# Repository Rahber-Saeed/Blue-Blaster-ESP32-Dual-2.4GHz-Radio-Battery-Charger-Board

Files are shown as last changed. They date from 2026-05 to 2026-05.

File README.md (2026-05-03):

# Blue-Blaster-ESP32-Dual-2.4GHz-Radio-Battery-Charger-Board
A custom open-source ESP32 development board featuring the WROOM-32E module, integrated TP4056 Li-Ion/Li-Po battery charging, dual E01-ML01DP5 (nRF24L01+) 2.4GHz wireless modules, USB-C with CH340C, and an onboard 0.96" OLED display. Designed for advanced wireless projects, robotics, and handheld controllers.
# 🔵 Blue Blaster - ESP32 Dual-Radio Dev Board

Blue Blaster PCB Render

The **Blue Blaster** is a feature-packed, custom ESP32 development board designed for advanced wireless communication projects. It combines the power of the ESP32-WROOM-32E with dual 2.4GHz radio modules (E01-ML01DP5), seamless USB-C connectivity, and robust Li-Ion/Li-Po battery management. 

This board is perfect for building DIY remote controllers, IoT sensor hubs, RC robotics, or any project requiring robust data transfer between multiple devices.

> ⚠️ **Note:** This project is currently in the prototyping/design phase. Please review the schematic and ensure it suits your needs before ordering the PCB.

---

## ✨ Key Features

*   **Main Controller:** ESP32-WROOM-32E (4MB Flash).
*   **Power Management:**
    *   TP4056 Li-Ion/Li-Po battery charger with status LEDs.
    *   AMS1117 3.3V voltage regulator for main logic.
*   **Connectivity:**
    *   **USB Type-C:** Handles both power and data via the CH340C USB-to-Serial chip.
    *   **Dual 2.4GHz Radio:** Two E01-ML01DP5 modules (compatible with nRF24L01+ and SX1280 ecosystem) enabling master/slave or node-to-node communication.
*   **User Interface:**
    *   0.96" I2C OLED Display.
    *   3x Tactile Buttons (UP, DOWN, SELECT) for menu navigation.
    *   Dedicated RESET and BOOT buttons.
*   **PCB Layout:** 2-layer board with surface-mount components.

---

## 🖥️ Gallery

| Schematic | PCB | 
Schematic_Blue_Blaster_2026-05-03

| :---: | :---: | 
Blue_Blaster_3D_Top_View

| Schematic 
Blue_Blaster_3D_Bottom_View

| PCB Top |
Blue_Blaster_2D_View

---

## 📌 Hardware Specifications

### ⚡ Power
*   **Input Voltage:** 5V (via USB-C) or 3.7V-4.2V Battery (via BAT pads)
*   **Onboard Charger:** TP4056 with a default 1A charging current.

### 🔌 Pinout / GPIO Mapping (ESP32)

| Peripheral | Signal | ESP32 GPIO |
| :--- | :--- | :--- |
| **OLED Display** | SDA (I2C Data) | IO21 |
| | SCL (I2C Clock) | IO22 |
| **Buttons** | UP | IO32 |
| | DOWN | IO33 |
| | SELECT | IO26 |
| | BOOT | IO0 |
| **Radio 1 (E01-ML01DP5)** | MISO | IO25 |
| | MOSI | IO23 |
| | SCK | IO19 |
| | CSN | IO17 |
| | CE | IO18 |
| | IRQ | IO16 |
| **Radio 2 (E01-ML01DP5)** | MISO | IO14 |
| | MOSI | IO12 |
| | SCK | IO13 |
| | CSN | IO15 |
| | CE | IO27 |
| | IRQ | IO04 |
| **USB/Serial** | RXD0 | IO3 |
| | TXD0 | IO1 |
| **Battery** | TP_VBAT | ADC (Internal) |

---

## 🛠️ Getting Started

### 1. **Fabricate the PCB**
You can use the provided `Gerber` files (if available in your repository) or download the `PCB_PCB_Blue_Blaster-copy-copy_2026-05-03.json` file and upload it to [EasyEDA](https://easyeda.com/) or [JLCPCB](https://jlcpcb.com/) to manufacture the board.

### 2. **Solder Components**
Use the Silkscreen and the provided PDF Schematic to assemble the board.

### 3. **Programming**
You can program this board using the **Arduino IDE** or **ESP-IDF** via the USB-C port.

*   **Install Driver:** Ensure you have the [CH340 driver](https://www.wch-ic.com/downloads/CH341SER_EXE.html) installed.
*   **Arduino Setup:**
    1. Install the ESP32 board package.
    2. Select `ESP32 Dev Module`.
    3. Connect via USB-C.

### 4. **Example Code (BLE Scan)**
Here is a quick snippet to verify flashing works:

```cpp
void setup() {
  Serial.begin(115200);
  pinMode(32, INPUT); // UP Button
}

void loop() {
  if(digitalRead(32) == LOW) {
    Serial.println("Button UP Pressed!");
  }
  delay(100);
}

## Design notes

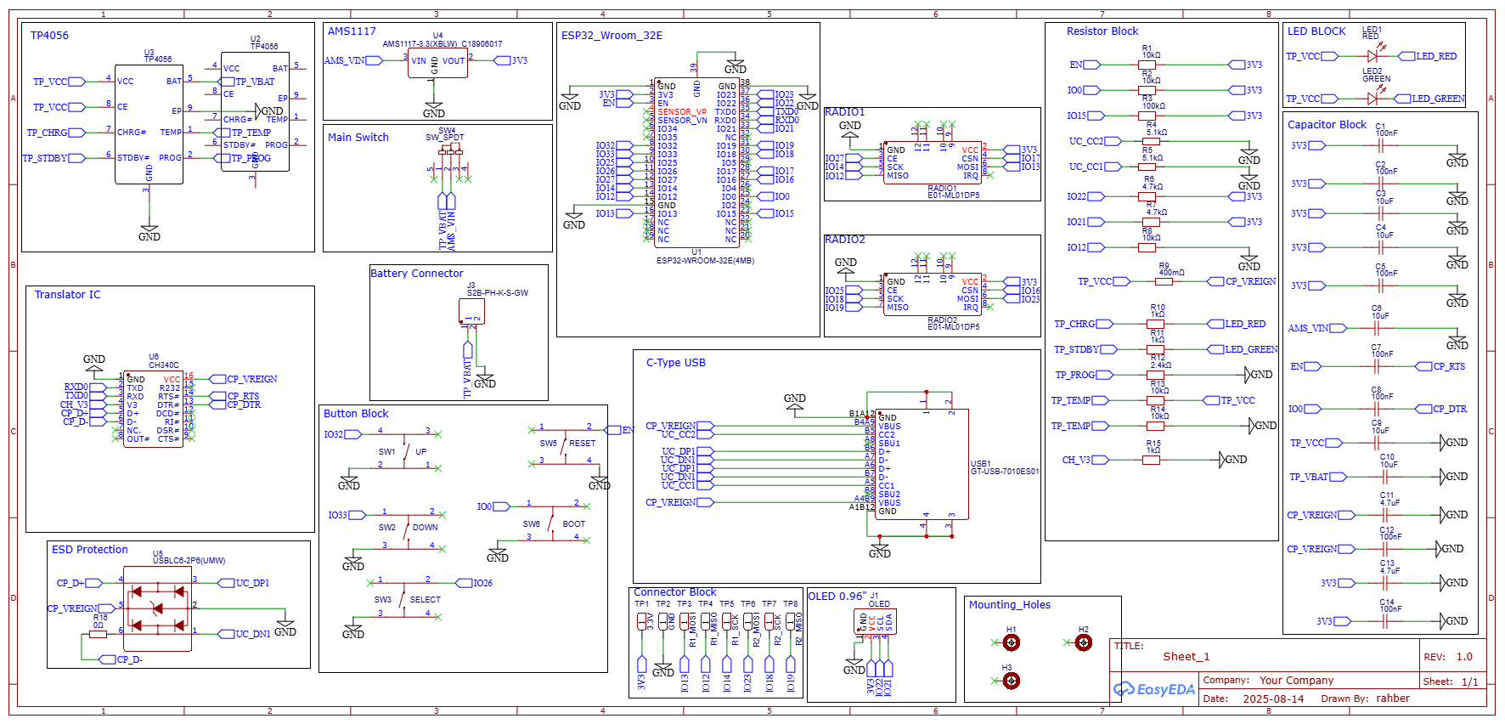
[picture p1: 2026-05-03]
Schematic_Blue_Blaster_2026-05-03.png

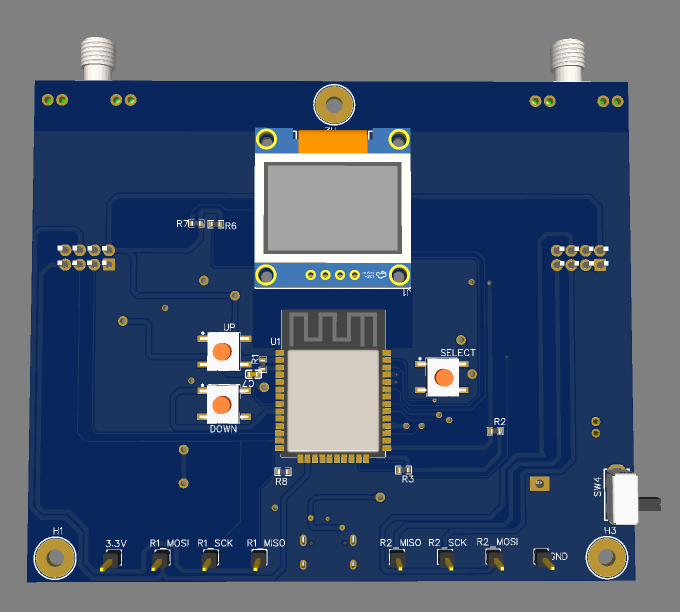
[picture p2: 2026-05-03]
Blue_Blaster_3D_Top_View.png

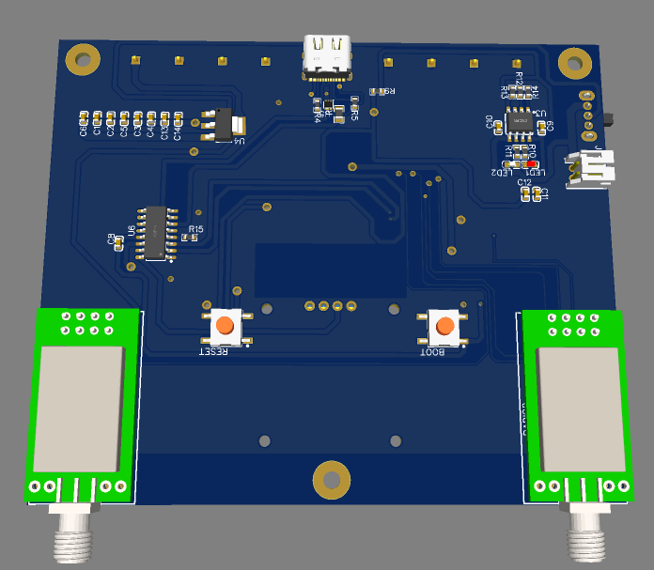
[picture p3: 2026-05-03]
Blue_Blaster_3D_Bottom_View.png

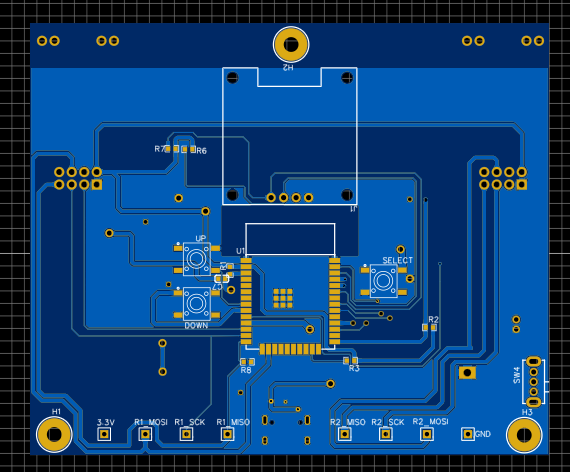
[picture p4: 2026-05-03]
Blue_Blaster_2D_View.png

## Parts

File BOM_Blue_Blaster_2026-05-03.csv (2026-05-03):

ID | Name | Designator | Footprint | Quantity | Manufacturer Part | Manufacturer | Supplier | Supplier Part | Price | Pins | 3DModel | Contributor | JLCPCB Part Class | description | link
1 | 100nF | C7,C8,C12,C1,C2,C5,C14 | C0603 | 7 | TCC0603X7R104J500CT | CCTC(三环) | LCSC | C282518 | 0.004 | 2 | C0603_L1.6-W0.8-H0.8 | LCSC | Extended Part |  | https://item.szlcsc.com/362304.html
2 | TP1 | 3.3V | HDR-M-2.54_1X1 | 1 |  |  | LCSC | C81276 | 0.014 | 1 | HDR-M-2.54_1x1 | LCEDA_Lib
3 | TP2 | GND | HDR-M-2.54_1X1 | 1 |  |  | LCSC | C81276 | 0.014 | 1 | HDR-M-2.54_1x1 | LCEDA_Lib
4 | TP4 | R1_MISO | HDR-M-2.54_1X1 | 1 |  |  | LCSC | C81276 | 0.014 | 1 | HDR-M-2.54_1x1 | LCEDA_Lib
5 | TP3 | R1_MOSI | HDR-M-2.54_1X1 | 1 |  |  | LCSC | C81276 | 0.014 | 1 | HDR-M-2.54_1x1 | LCEDA_Lib
6 | TP5 | R1_SCK | HDR-M-2.54_1X1 | 1 |  |  | LCSC | C81276 | 0.014 | 1 | HDR-M-2.54_1x1 | LCEDA_Lib
7 | TP8 | R2_MISO | HDR-M-2.54_1X1 | 1 |  |  | LCSC | C81276 | 0.014 | 1 | HDR-M-2.54_1x1 | LCEDA_Lib
8 | TP6 | R2_MOSI | HDR-M-2.54_1X1 | 1 |  |  | LCSC | C81276 | 0.014 | 1 | HDR-M-2.54_1x1 | LCEDA_Lib
9 | TP7 | R2_SCK | HDR-M-2.54_1X1 | 1 |  |  | LCSC | C81276 | 0.014 | 1 | HDR-M-2.54_1x1 | LCEDA_Lib
10 | SW2 | DOWN | SW-SMD_4P-L6.2-W6.5-P4.50-LS8.5 | 1 | TS-1157-C-E | XKB Connectivity(中国星坤) | LCSC | C609869 | 0.063 | 4 | SW-SMD_4P-L6.2-W6.5-H4.3-P4.50-LS8.5 | LCSC | Extended Part |  | https://item.szlcsc.com/639874.html
11 | SW3 | SELECT | SW-SMD_4P-L6.2-W6.5-P4.50-LS8.5 | 1 | TS-1157-C-E | XKB Connectivity(中国星坤) | LCSC | C609869 | 0.063 | 4 | SW-SMD_4P-L6.2-W6.5-H4.3-P4.50-LS8.5 | LCSC | Extended Part |  | https://item.szlcsc.com/639874.html
12 | SCREW-MOUNTING-HOLE-M4 | H1,H2,H3 | PKG-SCREW-MOUNTING-HOLE-3MM | 3 |  |  |  |  |  | 1 |  | Prof. Ing. F. Scordino |  | THT 3MM SCREW MOUNTING HOLE
13 | SW_SPDT | SW4 | SW-TH_SK12D07VG5-1 | 1 | SK12D07VG5 | SHOU HAN(首韩) | LCSC | C431548 | 0.023 | 5 | SW-TH_SK12D07VG5-1 | LCSC | Extended Part |  | https://item.szlcsc.com/datasheet/SK12D07VG5/427905.html
14 | ESP32-WROOM-32E(4MB) | U1 | WIFI-SMD_ESP32-WROOM-32E | 1 | ESP32-WROOM-32E-N4 | ESPRESSIF(乐鑫) | LCSC | C701341 | 3.782 | 47 | WIFI-SMD_L25.5-W18.0-H3.1-ESP32-WROOM-32E | LCSC | Extended Part |  | https://atta.szlcsc.com/upload/public/pdf/source/20220601/0020821B65DE5740BBACA5FACC5CF3B6.pdf
15 | OLED | J1 | OLED-TH_L27.8-W27.2-P2.54_C9900033791 | 1 | HS96L03W2C03 | HS(汉昇) | LCSC | C5248080 | 2.242 | 4 | OLED-TH_L27.8-W27.2-P2.54_C9900033791 | lcsc | Extended Part |  | https://img.jlc.com/image//data/smt-stock-produce/componentSizePhoto/2022-11-01/43d81eb4655044fe9599202a8cead0a7/BG2211010127_D22103102259_back.png
16 | SW1 | UP | SW-SMD_4P-L6.2-W6.5-P4.50-LS8.5 | 1 | TS-1157-C-E | XKB Connectivity(中国星坤) | LCSC | C609869 | 0.063 | 4 | SW-SMD_4P-L6.2-W6.5-H4.3-P4.50-LS8.5 | LCSC | Extended Part |  | https://item.szlcsc.com/639874.html
17 | 10kΩ | R1,R2,R8,R13,R14 | R0603 | 5 | SCR0603J10K | VO(翔胜) | LCSC | C3017715 | 0.001 | 2 | R0603 | lcsc | Extended Part |  | https://www.mouser.in/datasheet/2/447/PYu_RT_1_to_0_01_RoHS_L_11-1669912.pdf
18 | 100kΩ | R3 | R0603 | 1 | FRC0603J104 TS | FOJAN(富捷) | LCSC | C2907088 | 0.001 | 2 | R0603 | lcsc | Extended Part |  | https://www.mouser.in/datasheet/2/447/PYu_RT_1_to_0_01_RoHS_L_11-1669912.pdf
19 | 4.7kΩ | R6,R7 | R0603 | 2 | FRC0603J472 TS | FOJAN(富捷) | LCSC | C2907166 | 0.001 | 2 | R0603 | lcsc | Extended Part |  | https://www.mouser.in/datasheet/2/447/PYu_RT_1_to_0_01_RoHS_L_11-1669912.pdf
20 | 400mΩ | R9 | R0603 | 1 | RTT03R40JTP | RALEC(旺诠) | LCSC | C166742 | 0.004 | 2 | R0603 | LCSC | Extended Part |  | https://www.mouser.in/datasheet/2/447/PYu_RT_1_to_0_01_RoHS_L_11-1669912.pdf
21 | 0Ω | R16 | R0805 | 1 | RTT05000JTP | RALEC(旺诠) | LCSC | C103901 | 0.002 | 2 | R0805_L2.0-W1.3-H0.6 | lcsc | Extended Part |  | https://item.szlcsc.com/142685.html
22 | CH340C | U6 | SOP-16_L10.0-W3.9-P1.27-LS6.0-BL | 1 | CH340C | WCH(南京沁恒) | LCSC | C84681 | 0.58 | 16 | SOP-16_L9.9-W3.9-H1.5-LS6.0-P1.27 | lcsc | Extended Part |  | https://item.szlcsc.com/391677.html
23 | 4.7uF | C11,C13 | C0603 | 2 | FCC0603X475K6R3CT | FOJAN(富捷) | LCSC | C7419427 | 0.005 | 2 | C0603_L1.6-W0.8-H0.8 | lcsc | Extended Part |  | https://item.szlcsc.com/362304.html
24 | RED | LED1 | LED0603_RED | 1 | F.0603.00008/P2-0603R1TS2-06T-002 | TUOZHAN(拓展光电) | LCSC | C7496810 | 0.004 | 2 | LED0603_Red | lcsc | Extended Part |  | https://atta.szlcsc.com/upload/public/pdf/source/20221223/DF7A907A50EF7ED947DFF1DBF724950B.pdf
25 | GREEN | LED2 | LED0603-FD_GREEN | 1 | XL-J1608SYGC-06 | XINGLIGHT(成兴光) | LCSC | C48586672 | 0.013 | 2 | LED0603-FD_GREEN | lcsc | Extended Part |  | https://www.mouser.com/datasheet/2/445/150060GS75003-2907499.pdf
26 | 10uF | C3,C4,C9,C10,C6 | C0603 | 5 | C0603X5R106K6R3NT | SANYEAR(叁叶源) | LCSC | C475250 |  | 2 | C0603_L1.6-W0.8-H0.8 | LCSC | Extended Part |  | https://item.szlcsc.com/362304.html
27 | 1kΩ | R10,R11,R15 | R0603 | 3 | FRC0603J102 TS | FOJAN(富捷) | LCSC | C2907113 | 0.001 | 2 | R0603 | lcsc | Extended Part |  | https://www.mouser.in/datasheet/2/447/PYu_RT_1_to_0_01_RoHS_L_11-1669912.pdf
28 | 2.4kΩ | R12 | R0603 | 1 | FRC0603J242 TS | FOJAN(富捷) | LCSC | C2907118 | 0.001 | 2 | R0603 | lcsc | Extended Part |  | https://www.mouser.in/datasheet/2/447/PYu_RT_1_to_0_01_RoHS_L_11-1669912.pdf
29 | 5.1kΩ | R4,R5 | R0603 | 2 | RC0603JR-075K1L | YAGEO(国巨) | LCSC | C14677 | 0.002 | 2 | R0603 | lcsc | Extended Part |  | https://www.mouser.in/datasheet/2/447/PYu_RT_1_to_0_01_RoHS_L_11-1669912.pdf
30 | SW6 | BOOT | SW-SMD_4P-L6.2-W6.5-P4.50-LS8.5 | 1 | TS-1157-C-E | XKB Connectivity(中国星坤) | LCSC | C609869 | 0.063 | 4 | SW-SMD_4P-L6.2-W6.5-H4.3-P4.50-LS8.5 | LCSC | Extended Part |  | https://item.szlcsc.com/639874.html
31 | SW5 | RESET | SW-SMD_4P-L6.2-W6.5-P4.50-LS8.5 | 1 | TS-1157-C-E | XKB Connectivity(中国星坤) | LCSC | C609869 | 0.063 | 4 | SW-SMD_4P-L6.2-W6.5-H4.3-P4.50-LS8.5 | LCSC | Extended Part |  | https://item.szlcsc.com/639874.html
32 | S2B-PH-K-S-GW | J3 | CONN-TH_S2B-PH-K-S-GW | 1 | S2B-PH-K-S-GW | JST | LCSC | C157932 | 0.823 | 2 | CONN-TH_S2B-PH-K-S-GW | LCSC | Extended Part |  | https://item.szlcsc.com/169280.html
33 | E01-ML01DP5 | RADIO1,RADIO2 | WIRELM-TH_E01-ML01DP5 | 2 | E01-ML01DP5 | EBYTE(亿佰特) | LCSC | C97339 | 4.854 | 12 | WIRELM-TH_L33.4-W18.0-H12.8-E01-ML01DP5 | LCSC | Extended Part |  | https://item.szlcsc.com/98546.html
34 | GT-USB-7010ES01 | USB1 | USB-C-SMD_GT-USB-7010C | 1 | GT-USB-7010ES01 | G-Switch(品赞) | LCSC | C7275158 | 0.525 | 16 | USB-C-SMD_GT-USB-7010C | lcsc | Extended Part |  | https://atta.szlcsc.com/upload/public/pdf/source/20220407/276C2E8CEADC75D1A3BE3EA4074DCCE5.pdf
35 | TP4056 | U3 | ESOP-8_L4.9-W3.9-P1.27-LS6.0-BL-EP | 1 | TP4056-42-ESOP8 | TOPPOWER(南京拓微) | LCSC | C16581 | 0.186 | 9 | ESOP-8_L4.9-W3.9-H1.6-LS6.0-P1.27 | Guest | Extended Part |  | https://www.mornsun.cn/html/pdf/SCM1501B.html
36 | AMS1117-3.3(XBLW)_C18906017 | U4 | SOT-223-3_L6.5-W3.4-P2.30-LS7.0-BR-1 | 1 | AMS1117-3.3(XBLW) | XBLW(芯伯乐) | LCSC | C18906017 | 0.042 | 4 | SOT-223-3_L6.5-W3.4-P2.30-LS7.0-BR-1 | lcsc | Extended Part |  | https://atta.szlcsc.com/upload/public/pdf/source/20211227/BF7B926AD6144BCD20BD13D5B3E3EADC.pdf
37 | USBLC6-2P6(UMW) | U5 | SOT-563-6_L1.6-W1.2-P0.5-LS1.6-BL | 1 | USBLC6-2P6(UMW) | UMW(友台半导体) | LCSC | C29780639 | 0.065 | 6 | SOT-563-6_L1.6-W1.2-P0.5-LS1.6-BL | lcsc | Extended Part |  | https://img.jlc.com/pdf/applyPasteComponent/2021-07-20/95188D/73206044bea6400dba9e6528ad790ff5/ETA3521FSG.pdf

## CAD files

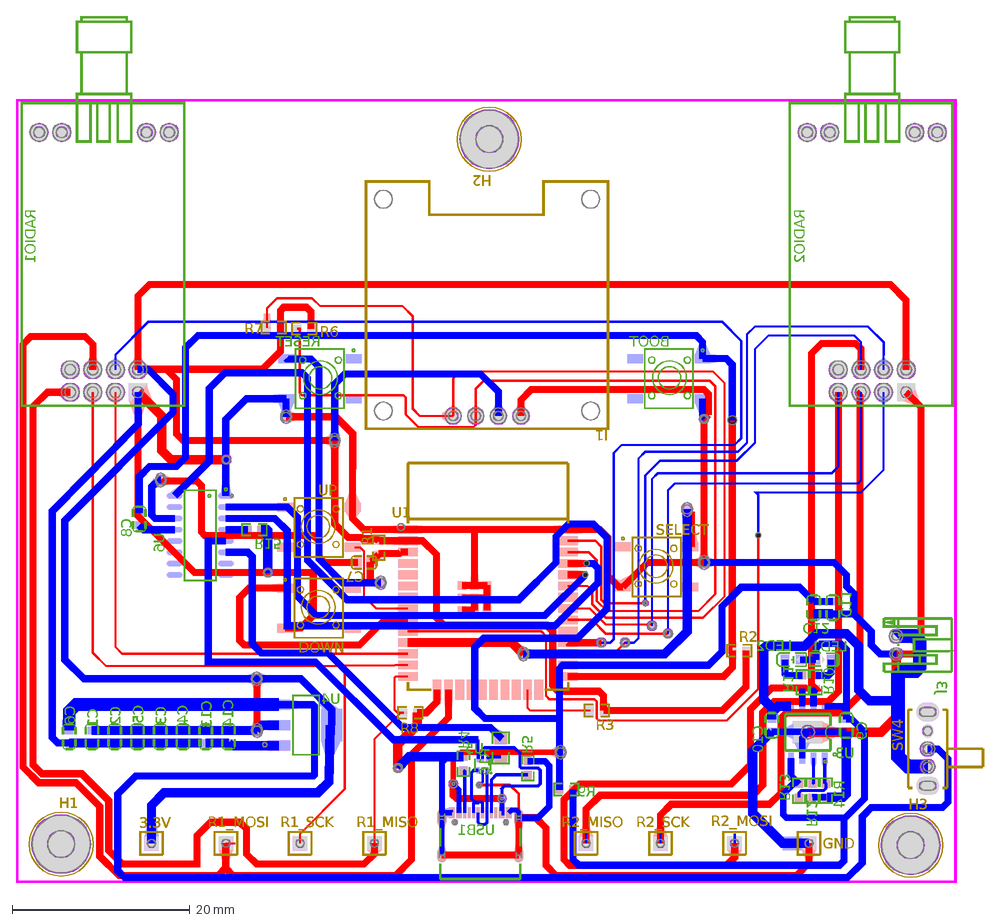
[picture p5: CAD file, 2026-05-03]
PCB_Blue_Blaster-copy-copy_2026-05-03.dxf
C7
3.3V
GND
R1_MISO
R1_MOSI
R1_SCK
R2_MISO
R2_MOSI
R2_SCK
DOWN
SELECT
H1
H2
SW4
U1
J1
H3
UP
R1
R2
R3
R6
R7
R8
C8
R9
R16
U6
C11
C12
LED1
LED2
C1
C2
C3
C4
C5
C9
C10
C13
C14
R10
R11
R12
R13
R14
R4
R5
R15
C6
BOOT
RESET
J3
RADIO1
RADIO2
USB1
U3
U4
U5

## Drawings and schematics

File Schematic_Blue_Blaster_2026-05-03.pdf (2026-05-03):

TP4056

AMS1117 | ESP32_Wroom_32E

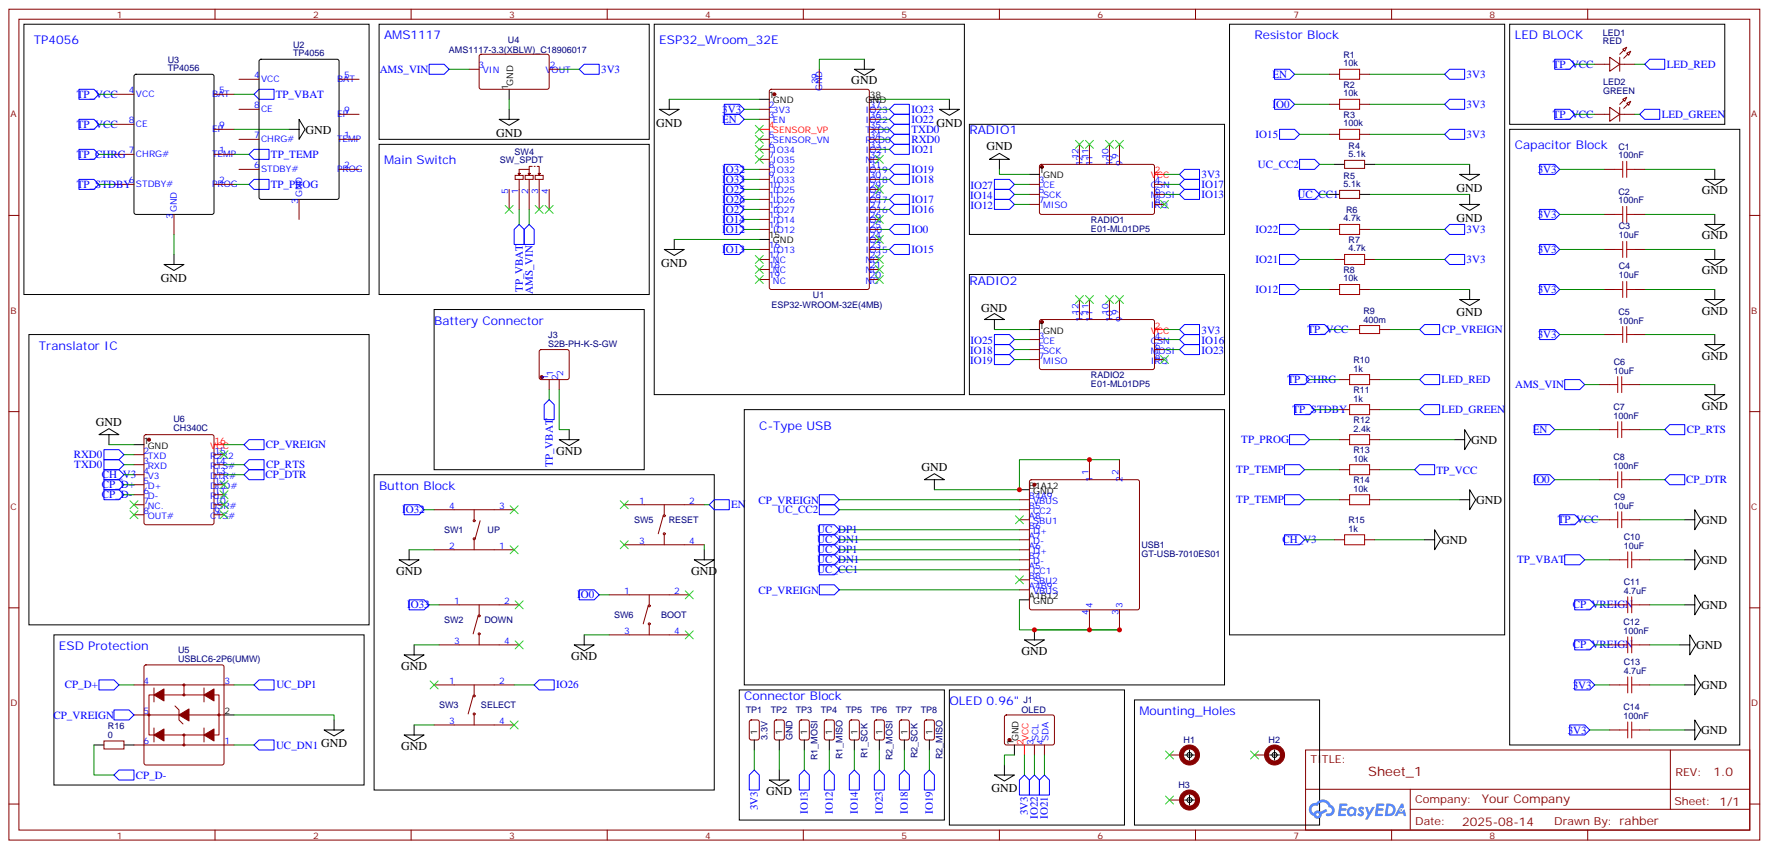
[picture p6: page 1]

DSR# 10 RI#11 DCD# 12 DTR# 13 RTS# 14 R232 15 VCC 16
